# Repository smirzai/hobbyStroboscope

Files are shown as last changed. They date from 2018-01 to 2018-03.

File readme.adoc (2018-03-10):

= Project specifications

* This project is a simple basic stroboscope using arduino and power LED's in its simplest form.
* The project can flash the power LED with frequencies from 1Hz to 50Khz. Duty cycle is fixed in the code.
* The stroboscope is fed by a 3 Cell 11.2v Lipo battery.
* The last used frequency is stored in EEPROM and will be restored with the device is turned on.

= Controls
* On/Off switch: cuts the main power when off
* Rotary switch push button: When the system starts, the cursor is on the most significant digit. Each pushing of push button, will move cursor to right. The cursor will roll to the most significant when it reaches the least significant digit.
* Rotary switch: Turning the rotary switch to right or left will increase and decrease the digit at the cursor respectively.
* Double push button: Pressing it doubles the frequency
* Half push button: pressin it halves the frequency

= Parts list
* https://store.arduino.cc/usa/arduino-nano[Arduino nano]
* https://www.infineon.com/cms/en/product/power/mosfet/20v-300v-n-channel-power-mosfet/80v-100v-n-channel-power-mosfet/irf540n/[IRF540N Mosfet]
* https://en.wikipedia.org/wiki/2N2222[2N2222 generic NPN transistor]
* 1K resisor
* 10K resistor
* http://www.ebay.de/itm/262467105661[10W power LED]
* LED heatsink
* https://www.ebay.com/itm/2-x-ALPS-EC11-Rotary-Encoder-30-Pulses-20mm-Shaft-PC-Mount-with-Push-on-Switch/252360818672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[Rotary swtich with PushButton]
* On/Off switch
* 3Cell Lipo Battery
* https://www.ebay.de/itm/Hot-Sale-BLACK-PLASTIC-ELECTRONICS-PROJECT-BOX-ENCLOSURE-CASE-100x60x25-mm-CJ/112557747586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[Plastic project box 10*6*25 mm]

= Hardware design
The schematic and breadboard diagram can be found in sketch.fzz using http://fritzing.org/home/[Fritzing] free tool.
10W LED needs around 11v. The current should be limitted to 1A on steady usage but can more current, maybe up to 10 A on very short bursts. If the 11.2 battery is directy connected to LED on steady state, there is a high chance of LED to burn. But as we only connect the battery to LED terminaln only in short bursts, it should be no problem.
A MOSFET is used to drive the current. In the test arduino could not provide enouph voltage for Mosfet to turn on. To increase the voltage a generic 2n2222 is used.
The pulse whichd drives the 2N2222 and Mosfet is generated accurately by Arduino.

= Arduino Stroboscope

== libraries used
http://www.mathertel.de/Arduino/RotaryEncoderLibrary.aspx (Rotary library)
https://github.com/adafruit/Adafruit_SSD1306 (SSD1306 library)
https://github.com/adafruit/Adafruit-GFX-Library (GFX library)

* I used this guide for driving OLED: http://www.instructables.com/id/Monochrome-096-i2c-OLED-display-with-arduino-SSD13/

= Schematics

Here is the breadboard diagram:

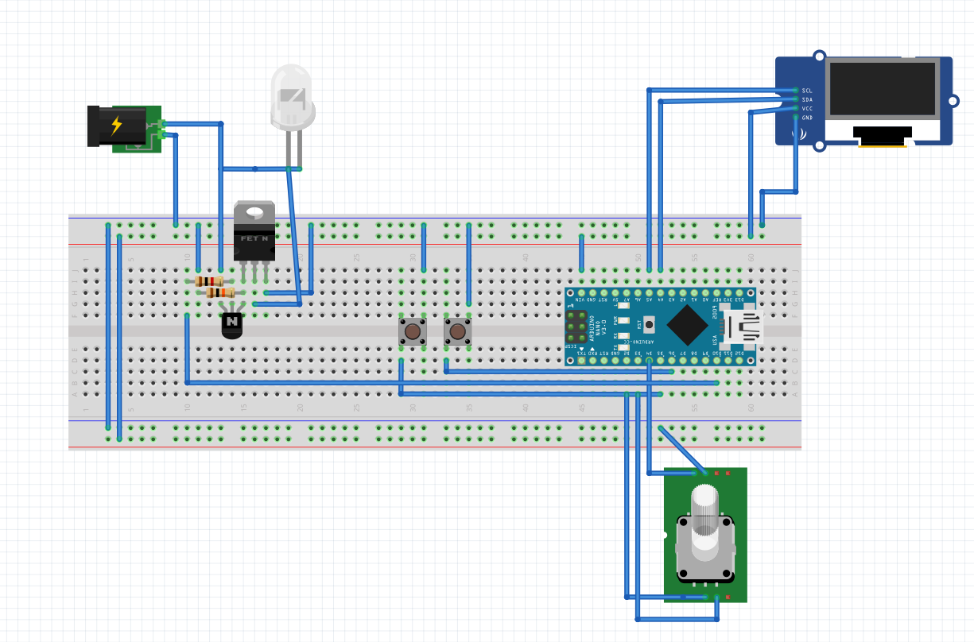
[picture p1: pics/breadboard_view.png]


and this is the schematics diagram:

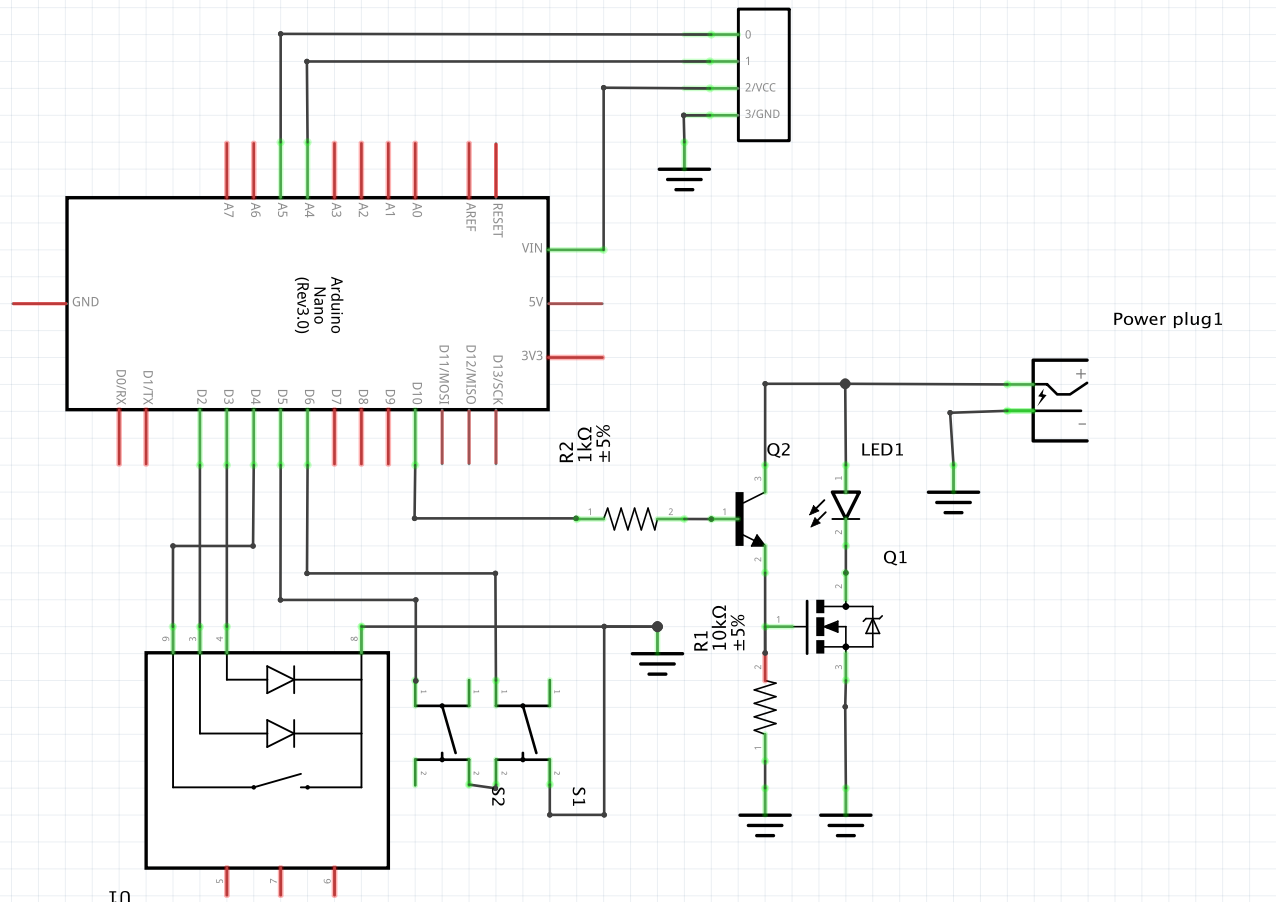
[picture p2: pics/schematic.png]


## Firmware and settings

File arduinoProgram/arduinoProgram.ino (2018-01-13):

/*********************************************************************
This is an example for our Monochrome OLEDs based on SSD1306 drivers

  Pick one up today in the adafruit shop!
  ------> http://www.adafruit.com/category/63_98

This example is for a 128x32 size display using I2C to communicate
3 pins are required to interface (2 I2C and one reset)

Adafruit invests time and resources providing this open source code, 
please support Adafruit and open-source hardware by purchasing 
products from Adafruit!

Written by Limor Fried/Ladyada  for Adafruit Industries.  
BSD license, check license.txt for more information
All text above, and the splash screen must be included in any redistribution
*********************************************************************/

#include <SPI.h>
#include <Wire.h>
#include <Adafruit_GFX.h>
#include <Adafruit_SSD1306.h>
#include "ModifiedRotaryEncoder.h"
#include <EEPROM.h>

#define OLED_RESET 4
Adafruit_SSD1306 display(OLED_RESET);

#define NUMFLAKES 10
#define XPOS 0
#define YPOS 1
#define DELTAY 2

#define ROTARY_SWITCH_PIN   4
#define LED_PIN 13
#define LOGO16_GLCD_HEIGHT 16 
#define LOGO16_GLCD_WIDTH  16 

#define DOUBLE_PIN 5
#define HALF_PIN 6

#define DEBOUNCE_TIME 100


#if (SSD1306_LCDHEIGHT != 32)
#error("Height incorrect, please fix Adafruit_SSD1306.h!");
#endif

long pos;
long eprom_timer;
int eprom_dirty;
ModifiedRotaryEncoder encoder(2, 3);


void tickInterrupt() {
 
  encoder.tick(); // just call tick() to check the state.
  Serial.println(encoder.getNonLinearPosition());
}

void update_frequency(long f) {
   
  display.clearDisplay();
  display.setTextSize(2);
  display.setTextColor(WHITE);
  display.setCursor(0,0);

  char buffer[10];
  sprintf(buffer, "%05lu", f);
  display.println(buffer);
  int step = encoder.getStep();
  int log = 5;
  while (step > 0) {
    step /= 10;
    --log;
  }
  
 
  display.drawLine(12 * log, 20, 12 * log + 10, 20, WHITE);
   
  display.display();

  setPwm(f) ;
  

   
}

void setup()   {                
  Serial.begin(9600);
  attachInterrupt(digitalPinToInterrupt(2), tickInterrupt, CHANGE);
  attachInterrupt(digitalPinToInterrupt(3), tickInterrupt, CHANGE);

  display.begin(SSD1306_SWITCHCAPVCC, 0x3C);  // initialize with the I2C addr 0x3C (for the 128x32)

  long eprom_value = EEPROM.read(0) + (((long) EEPROM.read(1)) << 8);
 
  encoder.setNonLinearPosition(eprom_value);
 
  pinMode(ROTARY_SWITCH_PIN, INPUT_PULLUP);

  pinMode(LED_PIN, OUTPUT);
  pinMode(DOUBLE_PIN, INPUT);
  pinMode(HALF_PIN, INPUT);
  digitalWrite(DOUBLE_PIN, HIGH);
  digitalWrite(HALF_PIN, HIGH);
 
  eprom_timer = millis();
  eprom_dirty = 0;
 
}

int last_rotary_switch_ts = 0;
int last_rotary_status = LOW;
int st = LOW;
int st1 = LOW;


void setPwm(long f) {
  TCCR1A =   _BV(COM1B1) | _BV(WGM10);  // PWM, Phase and Frequency Correct, Non Inverting
   
  DDRB |= _BV(PB1) | _BV(PB2); 
 
 long prescales[] = {1L, 8L, 64L, 256L, 1024L};

  int prescale = 0;
  long top;
  while (1) {
    top = 16000000 / (2L * prescales[prescale] * (long) f);
    if (top < 65536)
      break;
    prescale++;
    if (prescale >= 5) {
      break;
    }
  }; 
 
  TCCR1B =   (prescale + 1)| _BV(WGM13);  // no prescaling
  Serial.println(top);
  OCR1A = top;
  //  OCR1B = OCR1A / 2;
  long width = top / 70;
  Serial.println(width);
  Serial.println();
 
  OCR1B = width;

}

long dobounce_double = 0;
long debounce_half = 0;
int last_double = HIGH;
int last_half = HIGH;


void loop() {
 // encoder.tick();
 
  int rs =  digitalRead(ROTARY_SWITCH_PIN);
  if ((rs != last_rotary_status) && (millis() - last_rotary_switch_ts > 200)) {
    last_rotary_switch_ts = millis();
    last_rotary_status = rs;
    
    st = !st;
    if (st) { // rotary switch pressed
      encoder.tickSwitch();
      update_frequency(pos);
    }
  }
  
  long newPos = encoder.getNonLinearPosition();
  
 
 if (eprom_dirty && (millis() > eprom_timer + 1000)) {
   eprom_timer = millis();
   st1 = !st1;
   digitalWrite(LED_PIN, st1);
    
   
    eprom_dirty = 0;

    EEPROM.write(0, pos & 0xFF);
    EEPROM.write(1, pos >> 8);
    
 }
 
  if (pos != newPos) {
   
    update_frequency(newPos);
    pos = newPos;
    eprom_dirty = 1;
    eprom_timer = millis();
   
  }

  if (digitalRead(DOUBLE_PIN) != last_double) {    
    

    
    if (millis() - dobounce_double > DEBOUNCE_TIME) {
      if (last_double)
          encoder.dbl(); 
      last_double = !last_double;;
      dobounce_double = millis();
      digitalRead(DOUBLE_PIN);
    }
  } else
    dobounce_double = millis();
    
  if (digitalRead(HALF_PIN) != last_half) {    
    if (millis() - debounce_half > DEBOUNCE_TIME) {
      if (last_half)
          encoder.half(); 
      last_half = !last_half;
      debounce_half = millis();
    }
  } else
    debounce_half = millis();
  

   

 
    
  
}

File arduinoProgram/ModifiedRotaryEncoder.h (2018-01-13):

// -----
// ModifiedRotaryEncoder.cpp - Library for using rotary encoders.
// This class is implemented for use with the Arduino environment.
// Copyright (c) by Matthias Hertel, http://www.mathertel.de
// This work is licensed under a BSD style license. See http://www.mathertel.de/License.aspx
// More information on: http://www.mathertel.de/Arduino
// -----
// 18.01.2014 created by Matthias Hertel
// 17.06.2015 minor updates.
// -----

#include "Arduino.h"


#define LATCHSTATE 3
#define MAX 50000
#define MIN 0

class ModifiedRotaryEncoder
{
public:
  // ----- Constructor -----
  ModifiedRotaryEncoder(int pin1, int pin2);
  
  // retrieve the current position
  long  getPosition();

  long  getNonLinearPosition();

  // adjust the current position
  void setPosition(long newPosition);

  long getStep();

  void tickSwitch();

  void setNonLinearPosition(long n);

  void dbl();
  void half();

  // call this function every some milliseconds or by using an interrupt for handling state changes of the rotary encoder.
  void tick(void);

private:
  int _pin1, _pin2; // Arduino pins used for the encoder. 
  
  int8_t _oldState;
  
  long _position;     // Internal position (4 times _positionExt)
  long _positionExt;  // External position
  long nonLinearPosition;
  long  step;
};



// The array holds the values –1 for the entries where a position was decremented,
// a 1 for the entries where the position was incremented
// and 0 in all the other (no change or not valid) cases.

const int8_t KNOBDIR[] = {
  0, -1,  1,  0,
  1,  0,  0, -1,
  -1,  0,  0,  1,
0,  1, -1,  0  };


// positions: [3] 1 0 2 [3] 1 0 2 [3]
// [3] is the positions where my rotary switch detends
// ==> right, count up
// <== left,  count down


// ----- Initialization and Default Values -----

ModifiedRotaryEncoder::ModifiedRotaryEncoder(int pin1, int pin2) {
  
  // Remember Hardware Setup
  _pin1 = pin1;
  _pin2 = pin2;
  
  // Setup the input pins
  pinMode(pin1, INPUT);
  digitalWrite(pin1, HIGH);   // turn on pullup resistor

  pinMode(pin2, INPUT);
  digitalWrite(pin2, HIGH);   // turn on pullup resistor

  // when not started in motion, the current state of the encoder should be 3
  _oldState = 3;

  // start with position 0;
  _position = 0;
  _positionExt = 0;
  nonLinearPosition = MIN;
  step = 100000;
  
} // ModifiedRotaryEncoder()


long  ModifiedRotaryEncoder::getPosition() {
  return _positionExt;
} // getPosition()


long  ModifiedRotaryEncoder::getNonLinearPosition() {
  return nonLinearPosition;
}


void  ModifiedRotaryEncoder::setNonLinearPosition(long n) {
  if ((n > MAX))
    n = MAX;
  else if (n < MIN)
      n = MIN;
    else 
      nonLinearPosition = n;
} 

long  ModifiedRotaryEncoder::getStep() {
  return step;
}

void ModifiedRotaryEncoder::dbl() {
  setNonLinearPosition(2 * nonLinearPosition);
  
}

void ModifiedRotaryEncoder::half() {
  setNonLinearPosition( nonLinearPosition / 2);
}



void  ModifiedRotaryEncoder::tickSwitch() {
  if (step == 1) 
    step = 10000;
  else
    step /= 10;
} // getPosition()


void ModifiedRotaryEncoder::setPosition(long newPosition) {
  // only adjust the external part of the position.
  _position = ((newPosition<<2) | (_position & 0x03L));
  _positionExt = newPosition;
} // setPosition()


void ModifiedRotaryEncoder::tick(void)
{
  int sig1 = digitalRead(_pin1);
  int sig2 = digitalRead(_pin2);
  int8_t thisState = sig1 | (sig2 << 1);


  int old_position = _position;
  if (_oldState != thisState) {
    _position += KNOBDIR[thisState | (_oldState<<2)];


    if (thisState == LATCHSTATE) {
        
      int diff = (_position >> 2) - _positionExt;
      long new_value = nonLinearPosition + diff * step;
       
      if ((new_value > MIN) && (new_value < MAX)) {
          nonLinearPosition = new_value;
         
         
       } ;
       _positionExt = _position >> 2;
     
     
    }
      
    _oldState = thisState;
  } // if
} // tick()

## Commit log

2018-01-13 move project from hobby projects repository to hobbyStroboscope repository
    [sketch.fzz]
2018-01-13 update parts list
    [sketch.fzz]
2018-03-10 add circuit pictures
